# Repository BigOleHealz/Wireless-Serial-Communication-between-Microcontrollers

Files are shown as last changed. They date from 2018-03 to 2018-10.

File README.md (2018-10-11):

# **Introduction**

The purpose of this project is to wire a MDBT40 chip to wirelessly communicate with a MK20DX256VHL7 Cortex-M4 via Bluetooth 4.2, with the MK20 acting as the receiver ready to scroll text across an LED display while the MDBT40 acts as the remote writing characteristics to the receiver. To accomplish this, the MK20 is outfitted with a BT840 chip to handle Bluetooth communication.

In addition to the dedicated remote, a Bluetooth-enabled smart phone can be used to control the MK20 via our Android app. 

# **Usage**

### Mobile App
The app itself is rather intuitive. Upon first opening the app, the user will be shown a list of all device names within range that have a UUID matching one of the UUIDs in our predefined library. The predefined library ensures that the user will only be shown devices with BT840 chips with our software installed on them. At the time of pairing, the user's device will most likely be the only one within range so finding their device should be very straightforward. If another device is within range, the user may need to sort through the list to find theirs. The user only needs to complete this process once as the UUID of their device will be saved in the app for future use. After this, the phone will automatically connect to the BT840 chip upon launching of the app.

While connected, the user can send a message to the MK20 simply by tapping any of the buttons at the four corners of the screen. Obviously, the message sent will match the text on the button. The button text can be manually changed by long-pressing on the button itself, which clears the text from the button and raises the keyboard. 

In addition, voice functionality is available in the app by tapping the center button. If the message sends successfully, the car icon at the top of the display will zoom across the screen from right to left. If you do not see the car zoom across the screen, it is due to 1 of 3 reasons: either the mobile device is not properly paired to the display, the text input was determined to be aggressive and/or hostile, or the car raced across the screen so fast that you blinked and missed it.

### Remote
The remote features six buttons corresponding to six preset messages, as well as a central “confirm” or “send” button. It comes with an omni-directional swivel mount which allows users to adhere it to the dashboard or AC vent. It comes pre-paired with with BT840.

When one of the six buttons are pressed, a blue LED ring lights up next to the button to show the user which message has been activated. The user may then press the center button to send the message to the LED display. This 2-step process is designed mostly to prevent the user from accidentally sending the wrong message. Upon activation of the "send" button, the LED ring should sequentially light up blue until the entire ring is illuminated blue. The LEDs next to the activated button will turn to green and then fade away if the message sends successfully. However, they will turn red and fade away if an error was encountered.

### LED Display Board
Hardware installation of the LED display itself is fairly straightforward. Just mount it on your rear windshield by rotating the side panels 180° so that both suction cups face the same direction as the display. Simply place the suction cups against the inside of the rear windshield and lock the flaps on the opposite face of the panels. Then flip the switch on the rear of the enclosure to power on the device.

When the display board receives a message, it will display it for a maximum of 7 seconds so as not to distract the rear driver. However, the message will scroll faster for longer messages so that the rear driver gets to see the message twice before it disappears in case they missed it the first time.

# **Functionality**

### BT840
Using the BLEPeripheral, the BT840 is declared as a BLEPeripheral device named "peripheral" having BLEService named "service" with the UUID "19b11234e8f2537e4f6cd104768a1214" and a BLECharacteristic named "characteristic" with UUID "19b10000e8f2537e4f6cd104768a1214". Next, the advertisement UUID for peripheral is set to the UUID of service, the default value of characteristic is set to "BLE Character", and the device's local name is set to "BLE Device". Finally, we call Wire.begin() so that we can communicate with the MK20 via I2C.

In the loop() function a BLECentral named "other_device" is instantiated as a central to peripheral for each loop executed until a central is connected. While connected, LED_BUILTIN will light up and the BT840 will wait for the user to overwrite the value of characteristic. If overwritten, the string value of characteristic is converted into a char array and sent byte-by-byte to the MK20 via I2C over channel 9.

### MK20DX256VHL7
The script begins by setting all constants like the matrix height and width as well as instantiating an Adafruit_LIS3DH object named "lis". The Adafruit_LIS3DH library is for use with 3-axis accelerometers and present in this skit so that the text will scroll from right to left regardless of orientation. 

In the setup() function, a scrolling layer is added to the matrix so that the color, scroll speed, font size, etc. of the text can be customized. Constant settings are then set for matrix and scrollingLayer. Wire1 is instantiated on channel 9 to receive data from the BT840 (Wire1 because Wire is occupied by the accelerometer). Finally, the callback method receiveEvent is passed to Wire1.onReceive() to be executed any time the MK20 receives data from the BT840.

In loop() we simply call the setRotation() function which reads input from the accelerometer and sets the rotation accordingly, so that the text is right-side-up and scrolls from right to left.

# **Features**
The mobile app blocks any inflammatory statements from being sent to the board. It does so using an exhaustive library of aggressive and/or hostile terms stored locally on the app. This library includes everything from benign but negative adjectives like “dumb” and “stupid”, to curse words, to homophobic and racial slurs… The is NO reason drivers should need these words while trying to de-escalate aggressive situations. 

The app also features Google’s voice recognition software, allowing drivers to operate the device while keeping both hands on the wheel and their eyes on the road. Again, the voice functionality will flag any aggressive or inflammatory messages.

# **Required Software, Hardware, & Wiring**
### Arduino Libraries Required

* [NeoPixel](https://github.com/adafruit/Adafruit_NeoPixel)
* [SmartMatrix3](https://github.com/pixelmatix/SmartMatrix)
* [Software Serial](https://github.com/PaulStoffregen/SoftwareSerial)
* [BLEPeripheral](https://github.com/sandeepmistry/arduino-BLEPeripheral)
* [Wire](https://github.com/esp8266/Arduino/tree/master/libraries/Wire)
* [Adafruit_LIS3DH](https://github.com/adafruit/Adafruit_LIS3DH)
* [Adafruit_Sensor](https://github.com/adafruit/Adafruit_Sensor)

### Components Required
* [Teensy 3.2]( https://www.pjrc.com/store/teensy32.html)
* [nRF52832 Development Kit](https://www.nordicsemi.com/eng/Products/Bluetooth-low-energy/nRF52-DK)

* 2 x [64 x 32 LED Matrices](https://www.adafruit.com/product/2278)
* 2 x [TP4056 Charging Module](https://www.amazon.com/McIgIcM-Lithium-Charging-Protection-Functions/dp/B06XQRQR3Q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)
* [LM2596 XL6009](https://www.amazon.com/gp/product/B0129HYAW0/ref=oh_aui_search_detailpage?ie=UTF8&psc=1)
* 2 x [10uF Polarized Capacitor](https://www.amazon.com/uxcell-10uF-Radial-Electrolytic-Capacitor/dp/B00W8YAJ2A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)
* [LiPo Battery - 4000mAh](https://www.amazon.com/Ofeely-4000mah-Polymer-Battery-Rechargeable/dp/B00U8GFKR4)
* [LiPo Battery - 500 mAh](https://www.amazon.com/ADAFRUIT-INDUSTRIES-1578-Lithium-Polymer/dp/B00L0W61VO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)
* [16-Pin Ribbon Cable](https://www.amazon.com/Pc-Accessories-Connectors-2-Pack-Silver/dp/B01J4NN9LK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)
* [12 LED NeoPixel Ring](https://www.amazon.com/Pc-Accessories-Connectors-2-Pack-Silver/dp/B01J4NN9LK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)
* 7 x [Buttons](https://www.amazon.com/OCR-Tactile-Button-Momentary-Assortment/dp/B01MRP025V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)

# **Remote/Transmitter:**

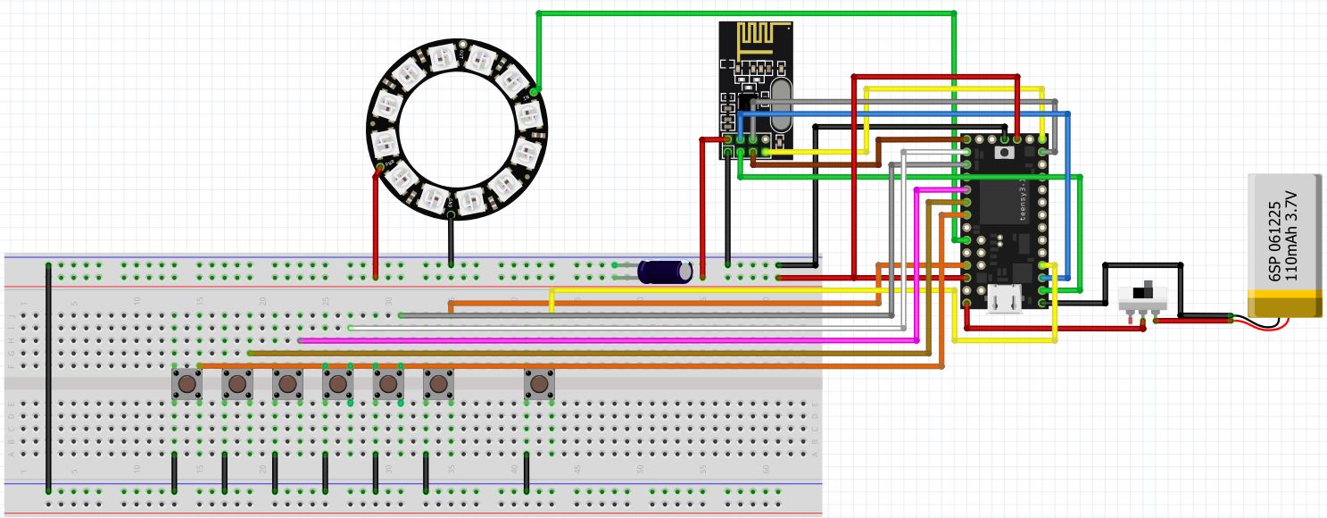
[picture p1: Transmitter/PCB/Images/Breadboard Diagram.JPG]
Remote Breadboard DGM


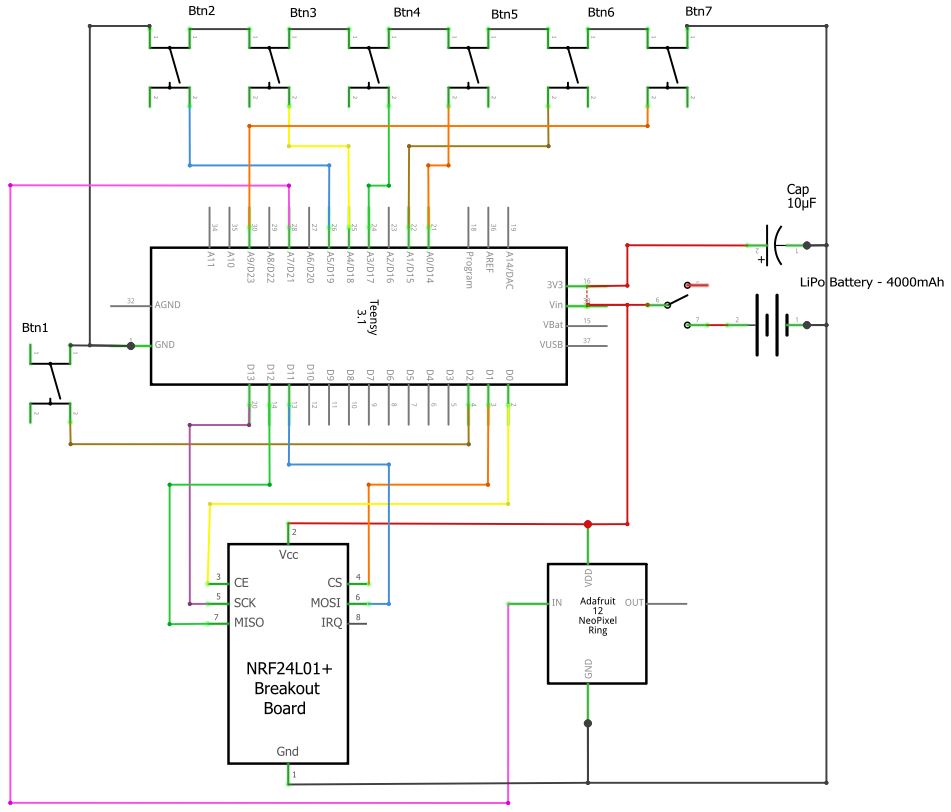
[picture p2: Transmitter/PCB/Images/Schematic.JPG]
Remote Schematic DGM


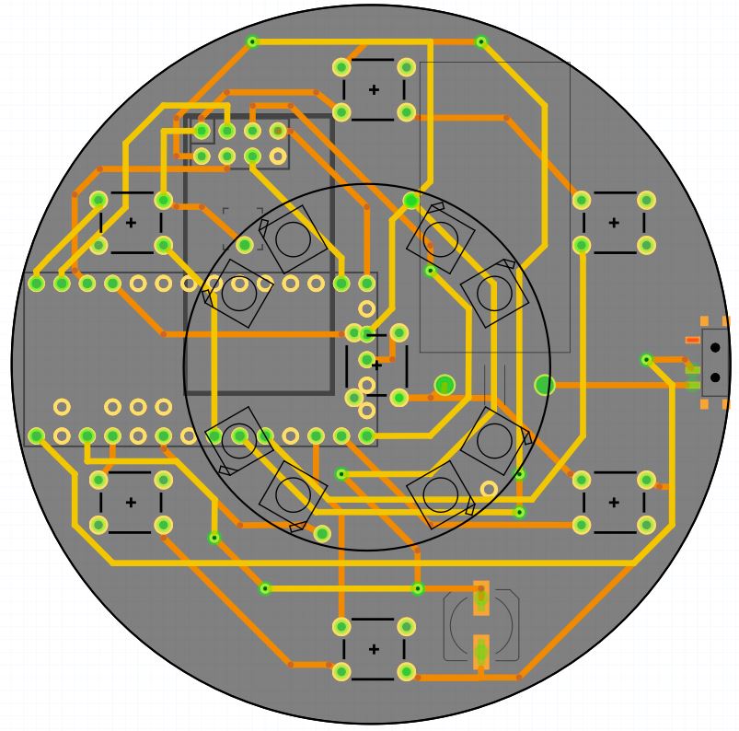
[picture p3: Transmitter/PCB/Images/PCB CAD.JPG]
Remote PCB DGM


# **Receiver:**

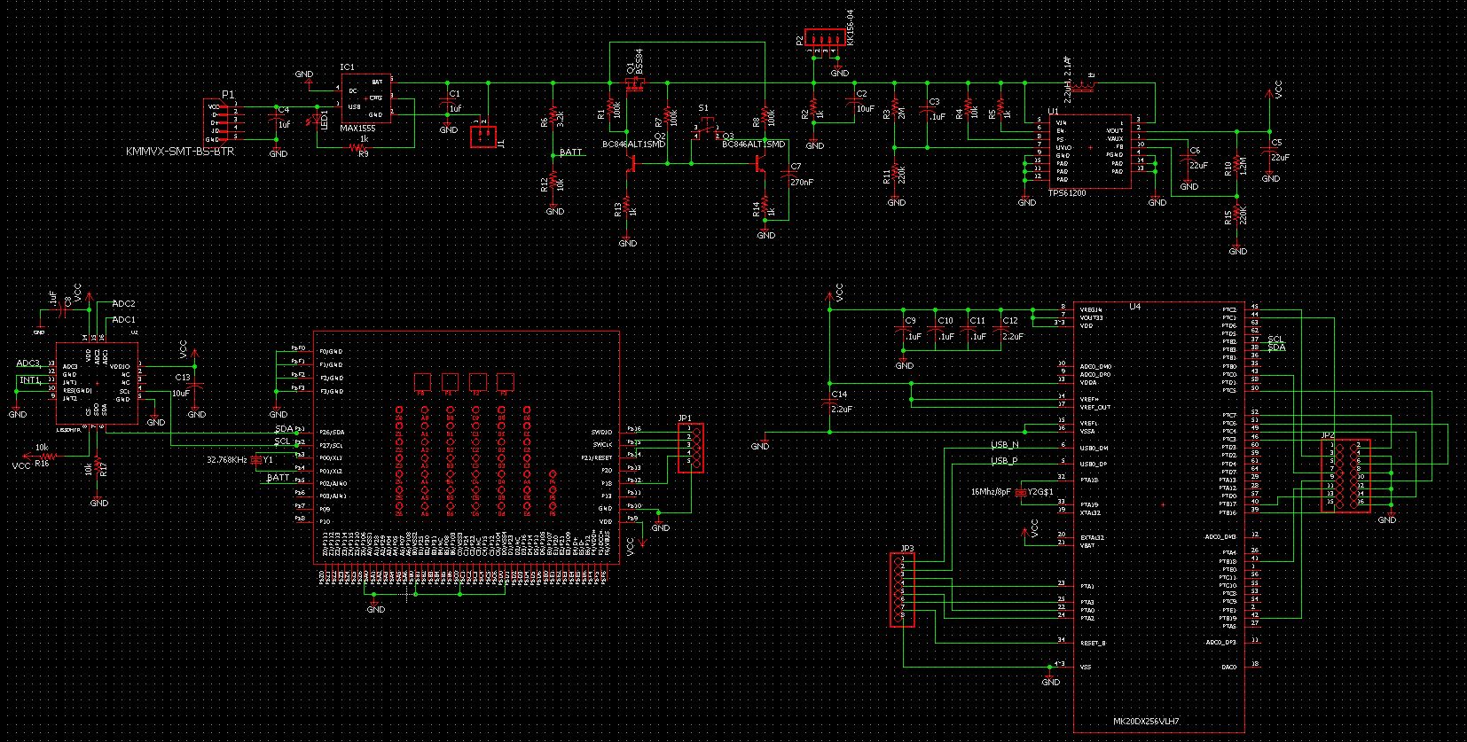
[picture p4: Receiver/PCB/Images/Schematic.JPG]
Receiver Schematic DGM


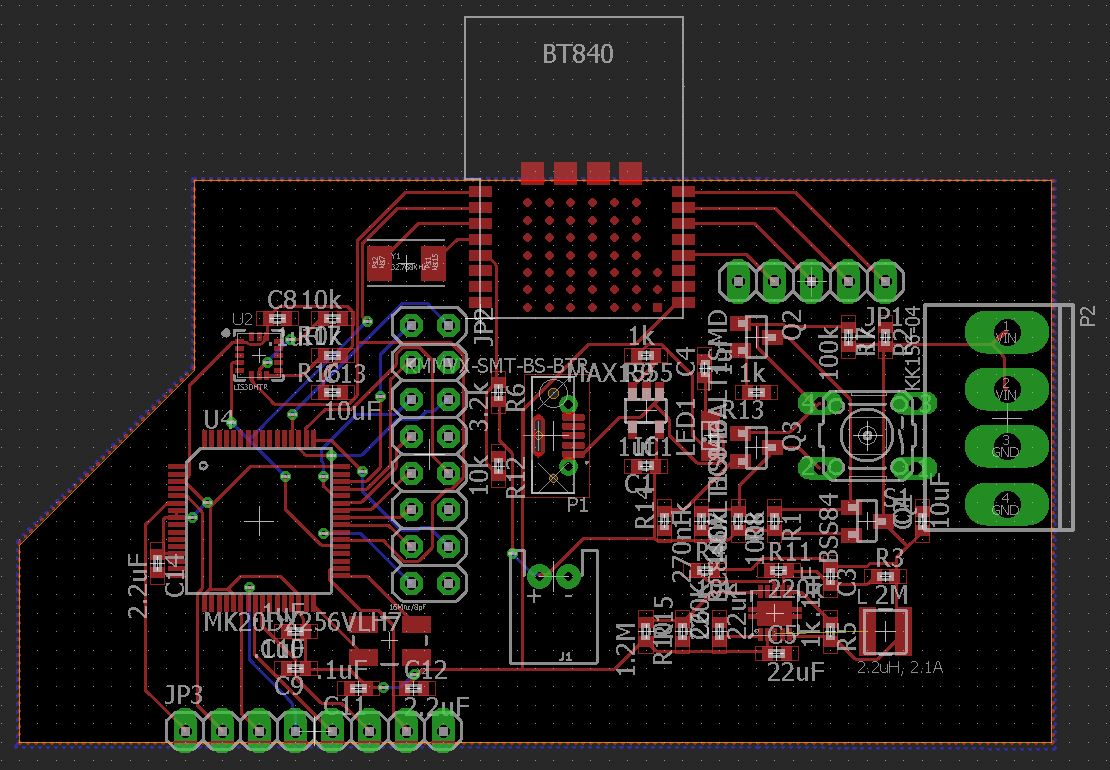
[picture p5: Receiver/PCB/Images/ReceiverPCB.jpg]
Receiver PCB DGM


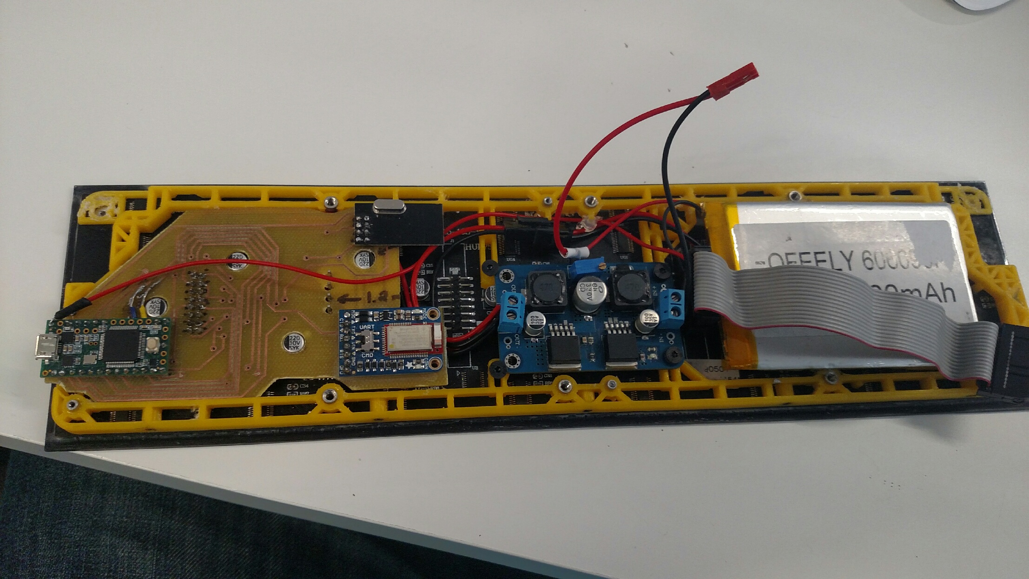
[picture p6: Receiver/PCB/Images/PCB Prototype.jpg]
Receiver Prototype


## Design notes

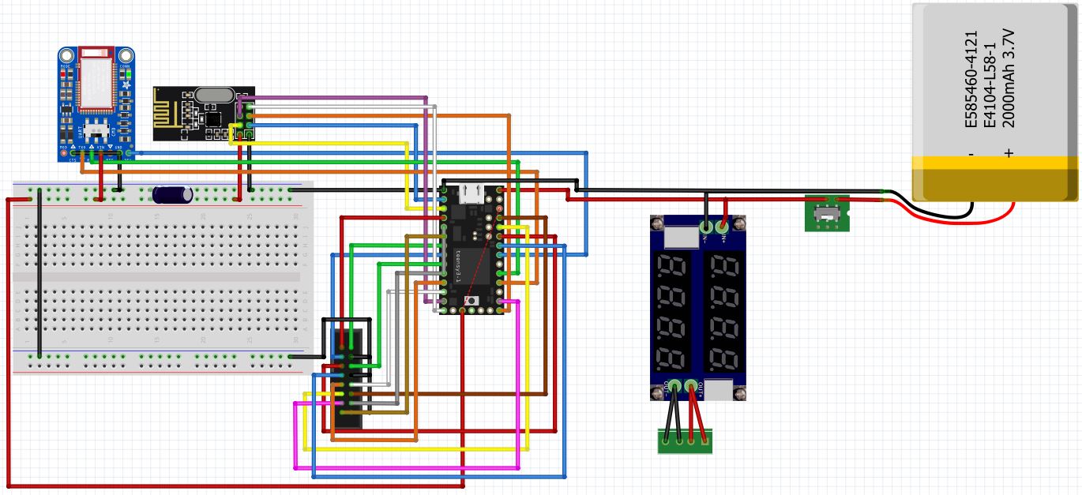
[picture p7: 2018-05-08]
Receiver/PCB/Images/Receiver BreadBoard.jpg

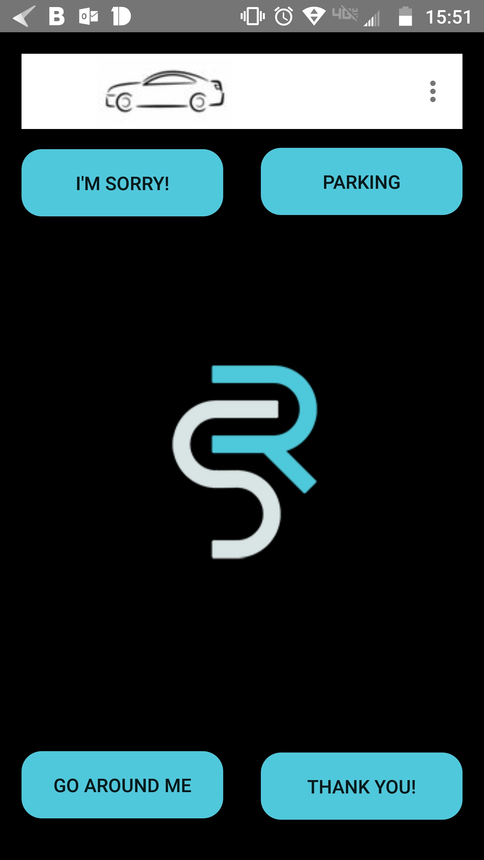
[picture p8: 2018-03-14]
App/RoadSage_Homescreen.png

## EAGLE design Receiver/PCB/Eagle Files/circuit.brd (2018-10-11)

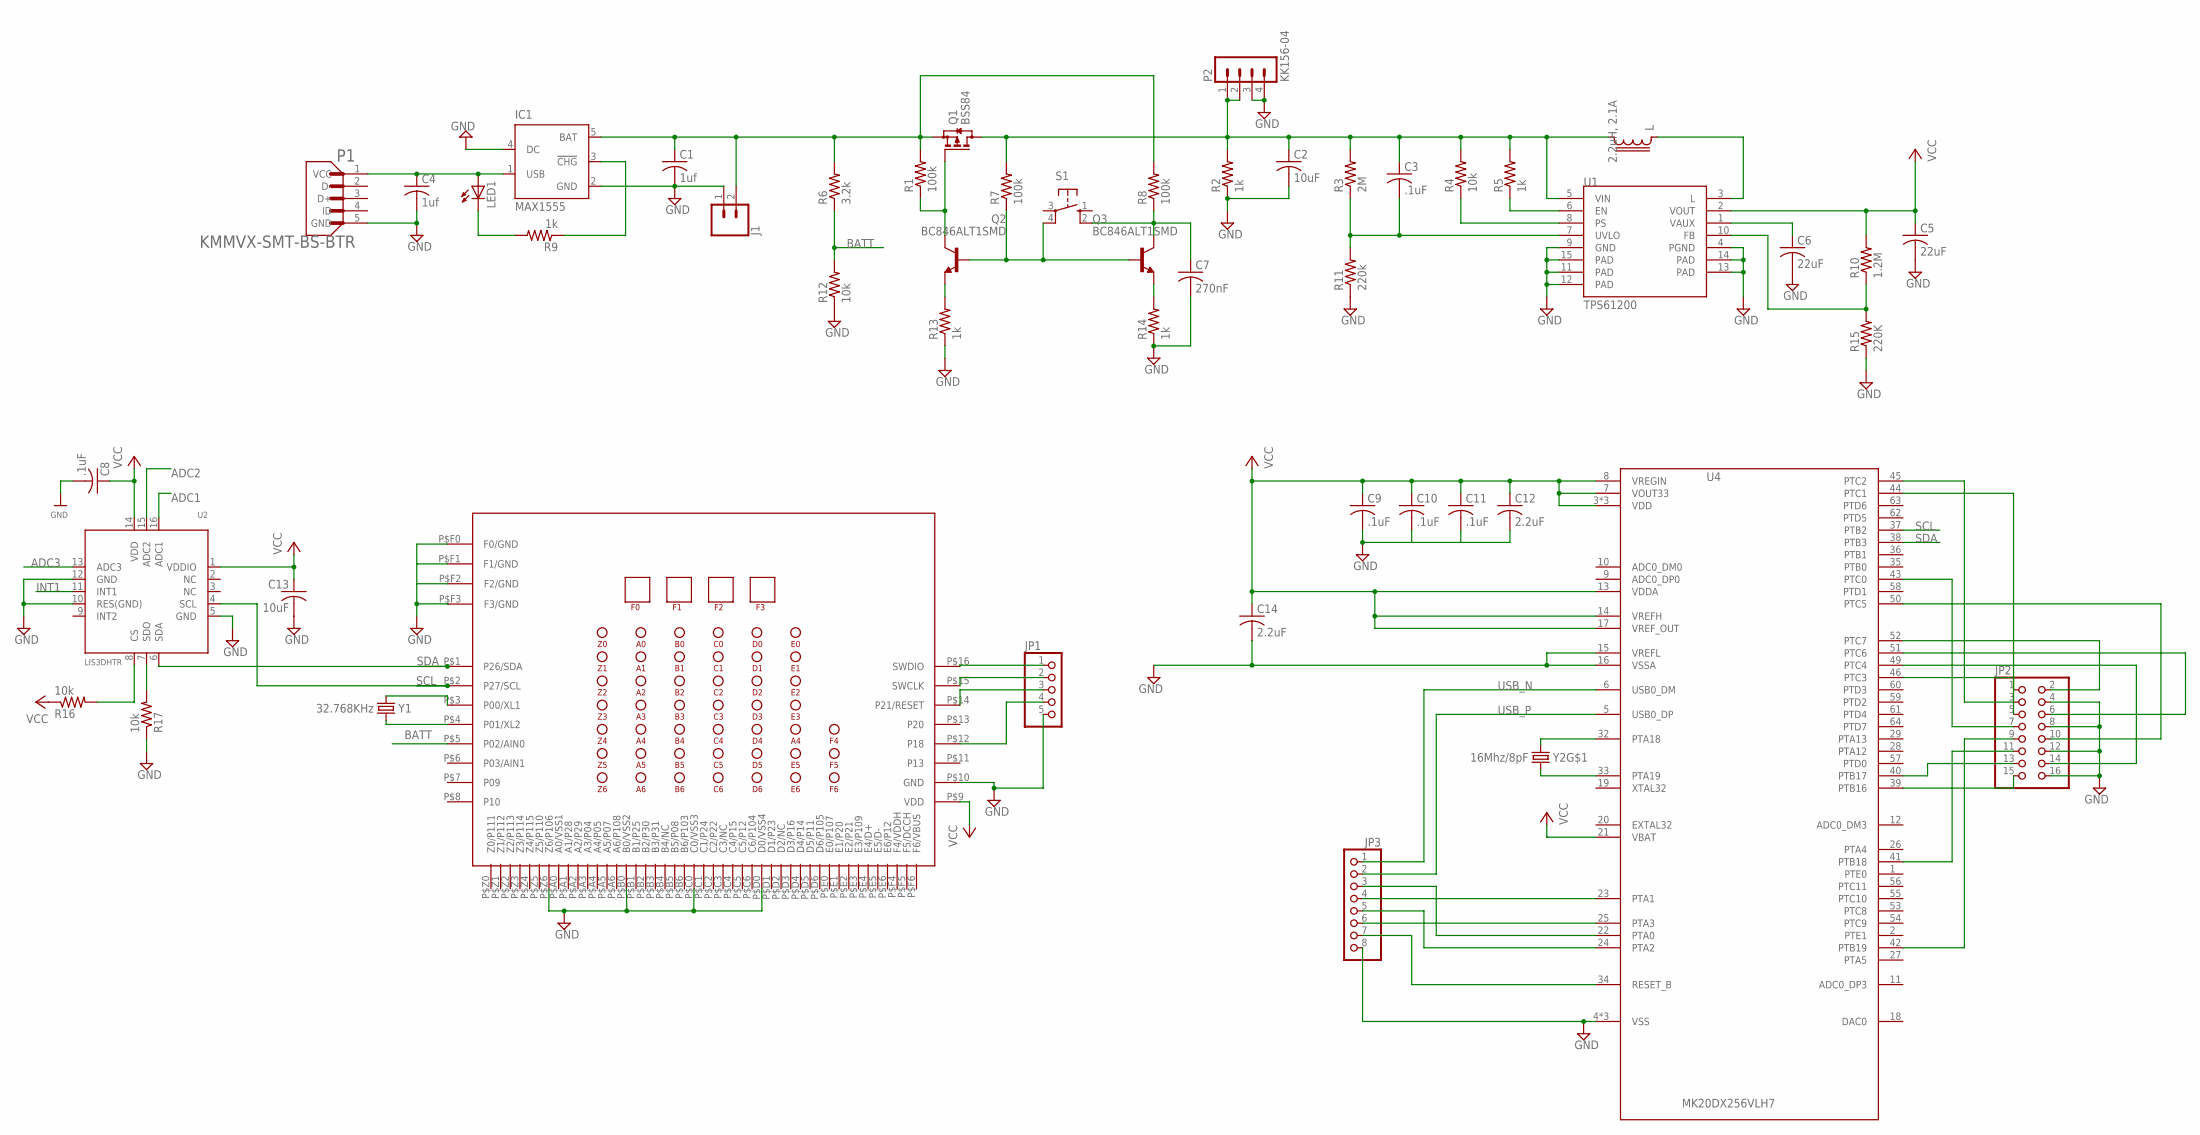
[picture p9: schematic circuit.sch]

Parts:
C1, C4: 1uf; C0402
C2, C13: 10uF; C0402
C3, C8, C9, C10, C11: .1uF; C0402
C5, C6: 22uF; C0402
C7: 270nF; C0402; MPN C1206C274K1RACTU
C12, C14: 2.2uF; C0402
IC1: MAX1555; SOT23-5L
J1: CONN_02-JST-2-PTH-NO_SILK; JST-2-PTH-NS
JP1: PINHD-1X5; 1X05
JP2: PINHD-2X8; 2X08
JP3: PINHD-1X8; 1X08
L: 2.2uH, 2.1A; LPS3015
LED1: LEDSML0805; SML0805
P1: KMMVX-SMT-BS-BTR; KYCON_KMMVX-SMT-BS-BTR
P2: KK156-04
Q1: BSS84; SOT23
Q2, Q3: BC846ALT1SMD; SOT23
R1, R7, R8: 100k; R0402
R2, R5, R9, R13, R14: 1k; R0402
R3: 2M; R0402
R4, R12, R16, R17: 10k; R0402
R6: 3.2k; R0402
R10: 1.2M; R0402
R11: 220k; R0402
R15: 220K; R0402
S1: 10-XX; B3F-10XX
U1: TPS61200; QFN-10_PAD
U2: LIS3DHTR; LGA16_3X3MM
U3: BT840
U4: MK20DX256VLH7
Y1: 32.768KHz; CRYSTAL-TXC-7A
Y2: 16Mhz/8pF; CRYSTAL-SMD-5X3

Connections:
ADC1: U2.16 (ADC1)
ADC2: U2.15 (ADC2)
ADC3: U2.13 (ADC3)
BATT: R6.1, R12.2, U3.P$5 (P02/AIN0)
GND: C1.2, C2.2, C4.2, C5.2, C6.2, C7.2, C8.2, C9.2, C10.2, C13.2, C14.2, IC1.2 (GND), IC1.4 (DC), J1.1, JP1.5, JP2.4, JP2.8, JP2.12, JP2.16, JP3.8, P1.5 (GND), P2.3, P2.4, R2.1, R11.1, R12.1, R13.1, R14.1, R15.1, R17.1, U1.4 (PGND), U1.9 (GND), U1.11 (PAD), U1.12 (PAD), U1.13 (PAD), U1.14 (PAD), U1.15 (PAD), U2.5 (GND), U2.10 (RES(GND)), U2.12 (GND), U3.P$10 (GND), U3.P$B0 (B0/VSS2), U3.P$C0 (C0/VSS3), U3.P$D0 (D0/VSS4), U3.P$F0 (F0/GND), U3.P$F1 (F1/GND), U3.P$F2 (F2/GND), U3.P$F3 (F3/GND), U3.P$Z6 (Z6/P106), U4.4 (VSS), U4.15 (VREFL), U4.16 (VSSA), U4.31 (VSS), U4.47 (VSS)
GND1: C11.2
GND2: C12.2
INT1: U2.11 (INT1)
unnamed: Q1.1 (G), Q2.3 (C), R1.1
unnamed: C7.1, Q3.3 (C), R8.1, S1.2 (S1)
unnamed: Q2.2 (E), R13.2
unnamed: Q2.1 (B), Q3.1 (B), R7.1, S1.4 (P1)
unnamed: Q3.2 (E), R14.2
unnamed: JP2.1, U4.46 (PTC3)
unnamed: U3.P$3 (P00/XL1), Y1.P$2 (2)
unnamed: C4.1, IC1.1 (USB), LED1.A, P1.1 (VCC)
unnamed: R16.2, U2.8 (CS)
unnamed: IC1.3 (!CHG), R9.1
unnamed: LED1.C, R9.2
unnamed: R17.2, U2.7 (SDO)
unnamed: L.1, U1.3 (L)
unnamed: JP3.3, U4.22 (PTA0)
unnamed: U3.P$4 (P01/XL2), Y1.P$1 (1)
unnamed: C3.2, R3.1, R11.2, U1.7 (UVLO)
unnamed: R4.1, U1.8 (PS)
unnamed: JP3.4, U4.23 (PTA1)
unnamed: R5.1, U1.6 (EN)
unnamed: C6.1, U1.1 (VAUX)
unnamed: JP3.5, U4.24 (PTA2)
unnamed: R10.1, R15.2, U1.10 (FB)
unnamed: JP3.6, U4.25 (PTA3)
unnamed: JP3.7, U4.34 (RESET_B)
unnamed: JP1.1, U3.P$16 (SWDIO)
unnamed: JP1.2, U3.P$15 (SWCLK)
unnamed: U4.32 (PTA18), Y2.3 (2)
unnamed: U4.33 (PTA19), Y2.1
unnamed: JP1.3, U3.P$14 (P21/RESET)
unnamed: JP1.4, U3.P$12 (P18)
unnamed: C1.1, IC1.5 (BAT), J1.2, Q1.2 (S), R1.2, R6.2, R8.2
unnamed: JP2.3, U4.45 (PTC2)
unnamed: JP2.5, U4.44 (PTC1)
unnamed: JP2.7, U4.43 (PTC0)
unnamed: JP2.9, U4.42 (PTB19)
unnamed: JP2.11, U4.41 (PTB18)
unnamed: JP2.13, U4.40 (PTB17)
unnamed: JP2.15, U4.39 (PTB16)
unnamed: JP2.14, U4.49 (PTC4)
unnamed: JP2.10, U4.50 (PTC5)
unnamed: JP2.6, U4.51 (PTC6)
unnamed: JP2.2, U4.52 (PTC7)
SCL: U2.4 (SCL), U3.P$2 (P27/SCL), U4.37 (PTB2)
SDA: U2.6 (SDA), U3.P$1 (P26/SDA), U4.38 (PTB3)
USB_N: JP3.1, U4.6 (USB0_DM)
USB_P: JP3.2, U4.5 (USB0_DP)
VCC: C5.1, C8.1, C9.1, C10.1, C11.1, C12.1, C13.1, C14.1, R10.2, R16.1, U1.2 (VOUT), U2.1 (VDDIO), U2.14 (VDD), U3.P$9 (VDD), U4.3 (VDD), U4.7 (VOUT33), U4.8 (VREGIN), U4.13 (VDDA), U4.14 (VREFH), U4.17 (VREF_OUT), U4.21 (VBAT), U4.30 (VDD), U4.48 (VDD)
VIN: C2.1, C3.1, L.2, P2.1, P2.2, Q1.3 (D), R2.2, R3.2, R4.2, R5.2, R7.2, U1.5 (VIN)

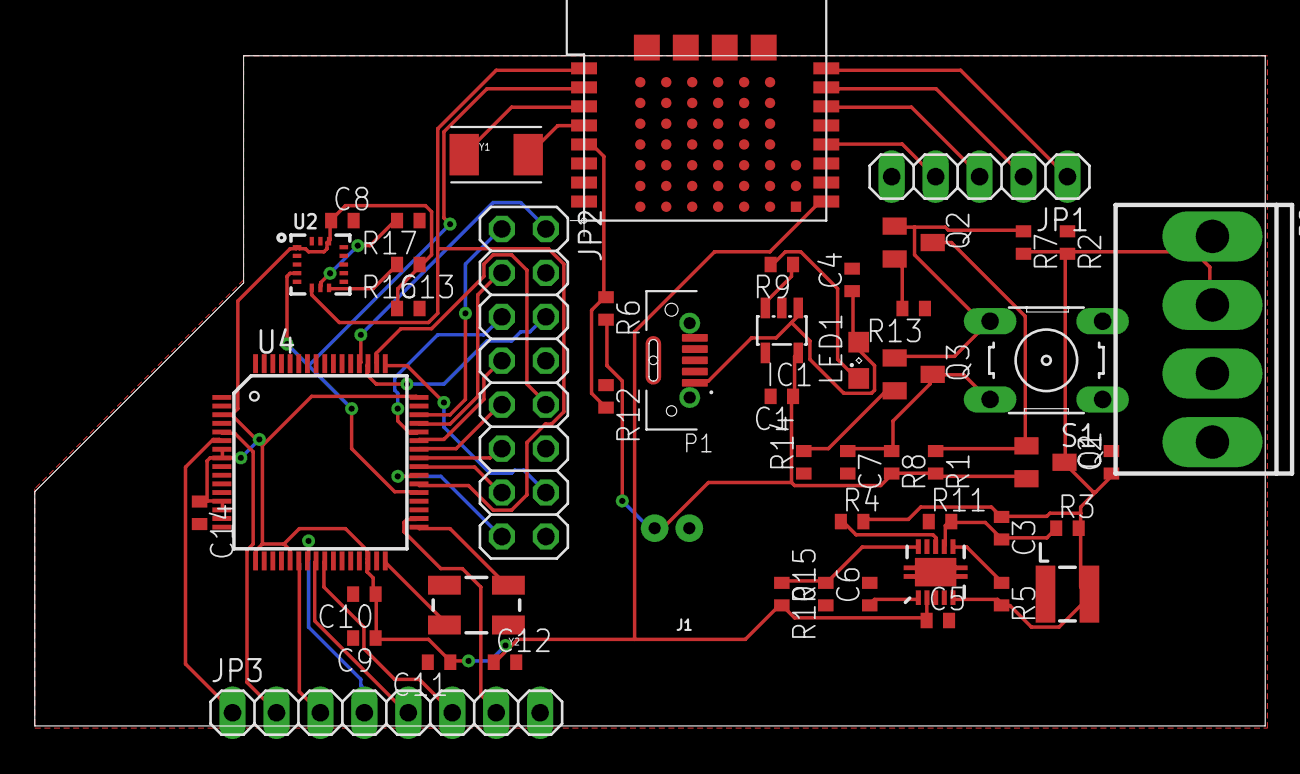
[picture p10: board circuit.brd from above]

Board: 2 copper layers, 71.1 x 38.7 mm, 50 parts (0 on the bottom side), 50 nets.

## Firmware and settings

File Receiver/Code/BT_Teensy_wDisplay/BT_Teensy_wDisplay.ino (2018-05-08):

#include <string.h>
#include <Arduino.h>
#include <SPI.h>
#if not defined (_VARIANT_ARDUINO_DUE_X_) && not defined (_VARIANT_ARDUINO_ZERO_)
#include <SoftwareSerial.h>
#endif
/*------------------------------------------------------------
                            Imports
  ------------------------------------------------------------*/
//------------------------- Bluefruit Stuff --------------------------
#include "Adafruit_BLE.h"
#include "Adafruit_BluefruitLE_SPI.h"
#include "Adafruit_BluefruitLE_UART.h"
#include "BluefruitConfig.h"
#define BUFSIZE                        128   // Size of the read buffer for incoming data
//-------------------------- LED Matrix Stuff -------------------------
#include <SmartMatrix3.h>
/*------------------------------------------------------------
          Define Constants and Initialize Components
  ------------------------------------------------------------*/
//-------------------------- Bluefruit Stuff -----------------
#define BLUEFRUIT_HWSERIAL_NAME Serial2
Adafruit_BluefruitLE_UART ble(BLUEFRUIT_HWSERIAL_NAME, BLUEFRUIT_UART_MODE_PIN);  // ...or hardware serial, which does not need the RTS/CTS pins. Uncomment this line
// function prototypes over in packetparser.cpp
uint8_t readPacket(Adafruit_BLE *ble, uint16_t timeout);
float parsefloat(uint8_t *buffer);
void printHex(const uint8_t * data, const uint32_t numBytes);
// the packet buffer
extern uint8_t packetbuffer[];
//-------------------------- LED Matrix Stuff -------------------------
#define COLOR_DEPTH 24                  // known working: 24, 48 - If the sketch uses type `rgb24` directly, COLOR_DEPTH must be 24
const uint8_t kMatrixWidth = 128;       // known working: 32, 64, 96, 128
const uint8_t kMatrixHeight = 32;       // known working: 16, 32, 48, 64
const uint8_t kRefreshDepth = 36;       // known working: 24, 36, 48
const uint8_t kDmaBufferRows = 4;       // known working: 2-4, use 2 to save memory, more to keep from dropping frames and automatically lowering refresh rate
const uint8_t kPanelType = SMARTMATRIX_HUB75_32ROW_MOD16SCAN;   // use SMARTMATRIX_HUB75_16ROW_MOD8SCAN for common 16x32 panels
const uint8_t kMatrixOptions = (SMARTMATRIX_OPTIONS_NONE);      // see http://docs.pixelmatix.com/SmartMatrix for options
const uint8_t kBackgroundLayerOptions = (SM_BACKGROUND_OPTIONS_NONE);
const uint8_t kScrollingLayerOptions = (SM_SCROLLING_OPTIONS_NONE);
const uint8_t kIndexedLayerOptions = (SM_INDEXED_OPTIONS_NONE);
SMARTMATRIX_ALLOCATE_BUFFERS(matrix, kMatrixWidth, kMatrixHeight, kRefreshDepth, kDmaBufferRows, kPanelType, kMatrixOptions);
SMARTMATRIX_ALLOCATE_BACKGROUND_LAYER(backgroundLayer, kMatrixWidth, kMatrixHeight, COLOR_DEPTH, kBackgroundLayerOptions);
SMARTMATRIX_ALLOCATE_SCROLLING_LAYER(scrollingLayer, kMatrixWidth, kMatrixHeight, COLOR_DEPTH, kScrollingLayerOptions);
SMARTMATRIX_ALLOCATE_INDEXED_LAYER(indexedLayer, kMatrixWidth, kMatrixHeight, COLOR_DEPTH, kIndexedLayerOptions);
const int defaultBrightness = 100 * (255 / 100); // full brightness
const int defaultScrollOffset = 6;
const rgb24 defaultBackgroundColor = {0x40, 0, 0};
String msg = "";

// -------------------------- Battery Stuff -----------------------------------------
#define batPin    A5
float measuredvbat = 0.0;
int iteration = 0;

void setup(void)
{
  // ----------------- Normal Arduino stuff for good practice -----------------
  Serial.begin(9600);
  //  while (!Serial);
  Serial.println("Starting!!");

  // -------------------------- Ble Stuff -------------------------------------
  Serial2.setRX(26);  // Set TXRX to bottom of teensy
  Serial2.setTX(31);
  /* Initialise the module */
  Serial.print(F("Initialising the Bluefruit LE module: "));
  if ( !ble.begin(VERBOSE_MODE) )
  {
    error(F("Couldn't find Bluefruit, make sure it's in CoMmanD mode & check wiring?"));
  }
  Serial.println( F("OK!") );

  Serial.println(F("Please use Adafruit Bluefruit LE app to connect in Controller mode"));
  /* Disable command echo from Bluefruit */
  ble.echo(false);
  Serial.println("Requesting Bluefruit info:");
  /* Print Bluefruit information */
  ble.info();
  Serial.println(F("Please use Adafruit Bluefruit LE app to connect in UART mode"));
  Serial.println(F("Then Enter characters to send to Bluefruit"));
  Serial.println();
  ble.verbose(false);  // debug info is a little annoying after this point!


  // -------------------------- LED Matrix Stuff  -------------------------------------
  matrix.addLayer(&backgroundLayer);
  matrix.addLayer(&scrollingLayer);
  matrix.addLayer(&indexedLayer);
  matrix.begin();
  matrix.setBrightness(defaultBrightness);
  scrollingLayer.setOffsetFromTop(defaultScrollOffset);
  backgroundLayer.enableColorCorrection(true);

}
void loop(void)
{
  // Wait for connection..............
  while (! ble.isConnected()) {

    //Put RF stuff inside of here

    delay(500);
  }
  char inputs[BUFSIZE + 1];
  //  if ( getUserInput(inputs, BUFSIZE) )
  //  {
  //    // Send characters to Bluefruit
  //    Serial.print("[Send] ");
  //    Serial.println(inputs);
  //    ble.print("AT+BLEUARTTX=");
  //    ble.println(inputs);
  //    // check response stastus
  //    if (! ble.waitForOK() ) {
  //      Serial.println(F("Failed to send?"));
  //    }
  //  }
//  ble.println("Iteration:     " + iteration);
  if (iteration == 9) {
    ble.print("Battery Life:   ");
    ble.println(2 * 3.3 * analogRead(batPin) / 1024);
  }
  // Check for incoming characters from Bluefruit
  ble.println("AT+BLEUARTRX");
  ble.readline();
  if (strcmp(ble.buffer, "OK") == 0) {
    // no data
    return;
  }
  // Some data was found, its in the buffer
  Serial.print(F("[Recv] "));
  Serial.println(ble.buffer);
  ble.waitForOK();
  /*
    // Check for incoming characters from Bluefruit
    ble.println("AT+BLEUARTRX");
    ble.readline();
    if (strcmp(ble.buffer, "OK") == 0) {
      //scrollText(str);
      //Serial.println("Success");
      return;
    }else{
    // Some data was found, its in the buffer
    Serial.print(F("[Recv] ")); Serial.println(ble.buffer);
    ble.waitForOK();
    msg = String(ble.buffer);
    }
    if (msg.length() > 0){
    const char * c = msg.c_str();

    scrollingLayer.setMode(wrapForward);
    scrollingLayer.setColor({0xff, 0xff, 0xff});
    scrollingLayer.setSpeed(30);
    scrollingLayer.setFont(gohufont14);
    scrollingLayer.setOffsetFromTop((kMatrixHeight/2) - 5);
    scrollingLayer.start(c, 2);
    }
  */

  iteration = (iteration + 1) % 10;}
void error(const __FlashStringHelper*err) {
  Serial.println(err);
  while (1);
}
bool getUserInput(char buffer[], uint8_t maxSize)
{
  // timeout in 100 milliseconds
  TimeoutTimer timeout(100);
  memset(buffer, 0, maxSize);
  while ( (!Serial.available()) && !timeout.expired() ) {
    delay(1);
  }
  if ( timeout.expired() ) return false;
  delay(2);
  uint8_t count = 0;
  do
  {
    count += Serial.readBytes(buffer + count, maxSize);
    delay(2);
  } while ( (count < maxSize) && (Serial.available()) );
  return true;
}

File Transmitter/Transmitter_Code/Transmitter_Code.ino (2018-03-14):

#include <SPI.h>
#include <stdio.h>
#include <RF24.h>
#include <Adafruit_NeoPixel.h>

//------------------ RF stuff ---------------------------

RF24 radio(0, 1);
byte addresses[][6] = {"1Node"};
unsigned long option = 0;
unsigned long scrool = 0;

//------------- Hardware Setup --------------------------
const int button1 = 18;
const int button2 = 17;
const int button3 = 14;
const int button4 = 15;
const int button5 = 23;
const int button6 = 19;
const int send_button = 2;
unsigned long msg = 0;

//------------------ NeoPixel Ring stuff ---------------------------

int num_pixels = 12;
int phase_shift = 4;
Adafruit_NeoPixel strip = Adafruit_NeoPixel(num_pixels, 21, NEO_GRB + NEO_KHZ800);


void setup() {
  // put your setup code here, to run once:
  Serial.begin(9600);
  while (!Serial) {}
  pinMode(button1, INPUT_PULLUP);
  pinMode(button2, INPUT_PULLUP);
  pinMode(button3, INPUT_PULLUP);
  pinMode(button4, INPUT_PULLUP);
  pinMode(button5, INPUT_PULLUP);
  pinMode(button6, INPUT_PULLUP);
  pinMode(send_button, INPUT_PULLUP);

    //--------------------------- RF Setup ---------------------------

  radio.begin();
  radio.setPayloadSize(8);
  radio.setChannel(0x4c);
  radio.setPALevel(RF24_PA_MAX);
  radio.openWritingPipe(addresses[0]);

  // Receiver :     radio.openReadingPipe(1,addresses[0]);

    //---------------------------- NeoPixel Ring stuff ---------------------------
  strip.begin();
  strip.setBrightness(100);
  strip.show();
  Serial.println("End of Startup. Starting Loop...");

  // Clear LED Ring
  blankStrip();
}

void loop() {
  // put your main code here, to run repeatedly:
  
  if ( digitalRead(button1) == LOW) {
    Serial.println("Button 1 Pressed");
    option = 1;
    selectLED(option);
  }
  if ( digitalRead(button2) == LOW) {
    Serial.println("Button 2 Pressed");
    option = 2;
    selectLED(option);
  }
  if ( digitalRead(button3) == LOW) {
    Serial.println("Button 3 Pressed");
    option = 3;
    selectLED(option);
  }
  if ( digitalRead(button4) == LOW) {
    Serial.println("Button 4 Pressed");
    option = 4;
    selectLED(option);
  }
  if ( digitalRead(button5) == LOW) {
    Serial.println("Button 5 Pressed");
    option = 5;
    selectLED(option);
  }
  if ( digitalRead(button6) == LOW) {
    Serial.println("Button 6 Pressed");
    option = 6;
    selectLED(option);
  }

// ------------------- On Send -----------------------
  if ( digitalRead(send_button) == LOW) {
    Serial.print("Send Button Pressed: ");
    Serial.println(option);
    
    sendLED(option);
    msg = option;

    //option = 0;

    if( radio.write(&option, sizeof(unsigned long))){
      confirmLED(option);
    } else {
      failLED(option);
    }
  }

  radio.write(&scrool, sizeof(unsigned long));
}



void blankStrip() {
  for (uint16_t i = 0; i < num_pixels; i++) {
    strip.setPixelColor(i, strip.Color(0, 0, 0));
  }
  strip.show();
}

// Select the 2 circles corresponding to the button

void selectLED(unsigned long option) {
  blankStrip();
  int start_light = (2 * option + phase_shift) % 12;
  strip.setPixelColor((start_light + 12 - 1) % 12, strip.Color(0, 0, 47));
  strip.setPixelColor(start_light, strip.Color(0, 0, 255));
  strip.setPixelColor(start_light + 1, strip.Color(0, 0, 47));
  strip.show();
}

// Fill circle with green to signify success

void confirmLED(unsigned long option) {
  blankStrip();
  int start_light = ((2 * option + phase_shift) % 12);
  strip.setPixelColor((start_light + 12 - 1) % 12, strip.Color(0, 47, 0));
  strip.setPixelColor(start_light, strip.Color(0, 255, 0));
  strip.setPixelColor(start_light + 1, strip.Color(0, 47, 0));
  strip.show();

  for (int i = 255; i > 0; i--) {
    strip.setPixelColor((start_light + 12 - 1) % 12, strip.Color(0, i, 0));
    strip.setPixelColor(start_light, strip.Color(0, i, 0));
    strip.setPixelColor(start_light + 1, strip.Color(0, i, 0));
    strip.show();
    delay(10);
  }
}

// Fill circle with red to signify failure

void failLED(unsigned long option) {
  blankStrip();
  int start_light = (2 * option + phase_shift) % 12;
  strip.setPixelColor((start_light + 12 - 1) % 12, strip.Color(47, 0, 0));
  strip.setPixelColor(start_light, strip.Color(255, 0, 0));
  strip.setPixelColor(start_light + 1, strip.Color(47, 0, 0));
  strip.show();

  for (int i = 255; i > 47; i--){
    strip.setPixelColor(start_light, strip.Color(i, 0, 0));
    strip.show();
    delay(10);
  }

  for (int i = 47; i > 0; i--) {
    strip.setPixelColor((start_light + 12 - 1) % 12, strip.Color(i, 0, 0));
    strip.setPixelColor(start_light, strip.Color(i, 0, 0));
    strip.setPixelColor(start_light + 1, strip.Color(i, 0, 0));
    strip.show();
    delay(10);
  }
}

// Fill circle with blue

void sendLED(unsigned long option) {
  int start_light = ((2 * option + phase_shift) % 12);

  for (int i = start_light; i < num_pixels + start_light; i++) {
    strip.setPixelColor(i % num_pixels, strip.Color(0, 0, 127));
    strip.show();
    delay(50);
    strip.setPixelColor(i % num_pixels, strip.Color(0, 0, 255));
    strip.show();
    delay(50);
  }

  // If message sent successfully...
  blankStrip();
  option = 50;
}

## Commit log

2018-03-14 App, Codes, PCB, Schematic, & Screenshots
    Android app, Fritzing and Gerber files, Microcontroller codes,
    Screenshots of breadboard diagram, schematic, PCB, and physical
    prototype
    [Controller4.6.fzz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]
2018-03-26 Added README.md file
    Updated some of the pictures, but mostly just added the README.md
    [Controller4.6.fzz, Receiver.fzz, Transmitter.fzz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]
2018-05-08 5-8-2018
    Update README.md, Delete extra HTML files, Tidy up images
    [Transmitter.fzz, Transmitter1.fzz]
2018-09-28 Updated Fritzing Files
    [Receiver.fzz]
2018-10-11 Production Version Summary
    Describes product down to chip level. Includes scripts for BT840 and
    MK20 as well as Eagle .sch and .brd files and gerber files.
    Still needed: MDBT40 Eagle files and scripts
    [RoadSageReceiver2.0_contour.gm1, RoadSageReceiver2.0_copperBottom.gbl, RoadSageReceiver2.0_copperTop.gtl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]

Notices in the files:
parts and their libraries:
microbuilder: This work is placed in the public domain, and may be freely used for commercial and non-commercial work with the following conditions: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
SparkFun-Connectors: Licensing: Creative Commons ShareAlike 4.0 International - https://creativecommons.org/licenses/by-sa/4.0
